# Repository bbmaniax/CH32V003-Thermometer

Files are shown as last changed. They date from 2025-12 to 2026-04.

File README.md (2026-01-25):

# Arduino: CH32V003-Thermometer

グラフ表示に対応したコンパクトな温度計です。

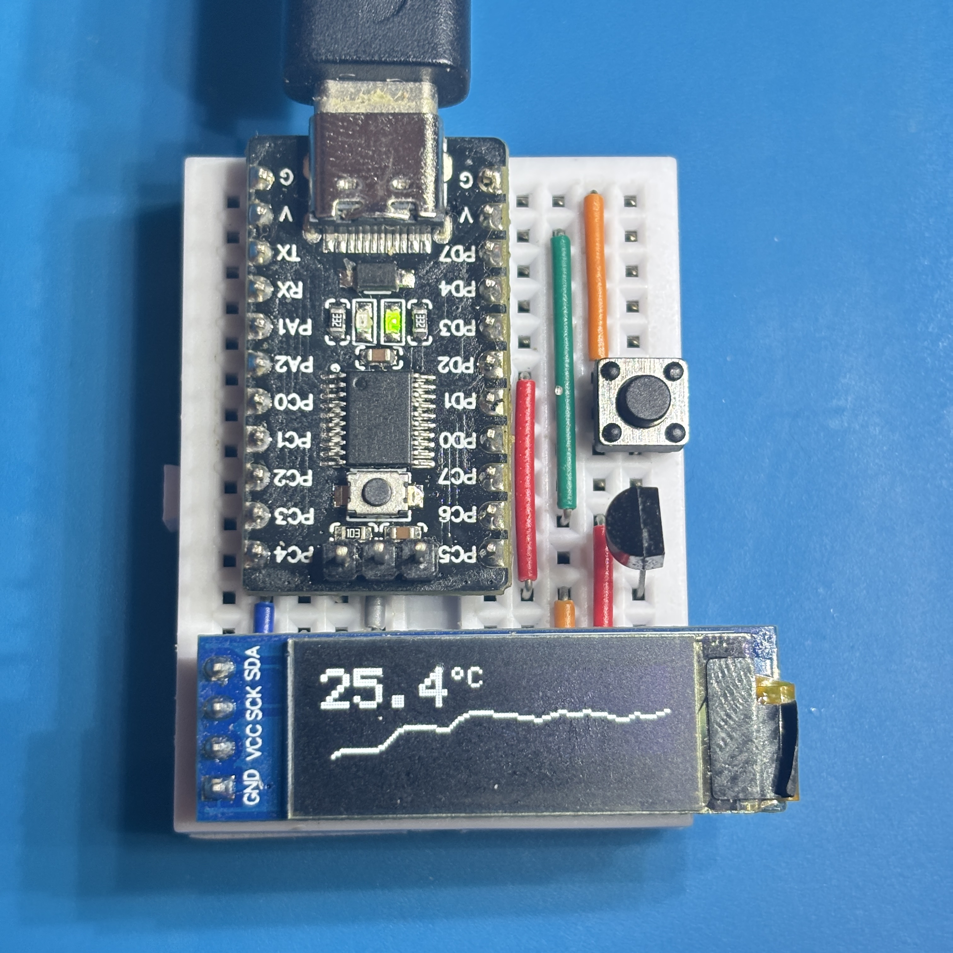
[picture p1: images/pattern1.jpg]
グラフ表示


温度のグラフ表示とテキスト表示、および上下反転表示に対応しています。

<div>
グラフ表示
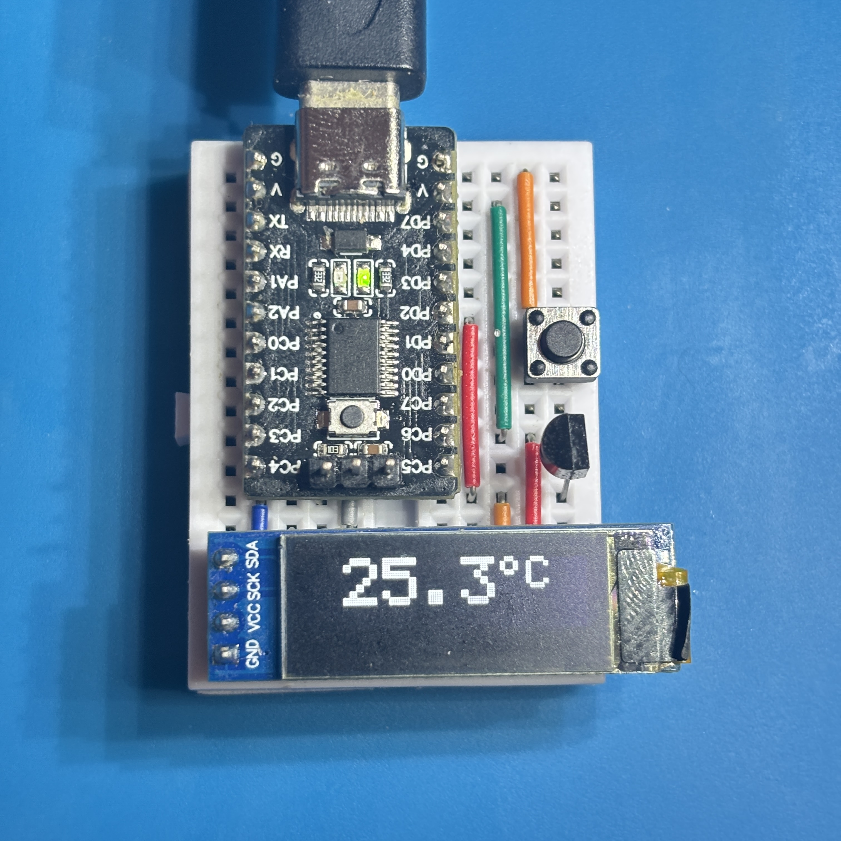
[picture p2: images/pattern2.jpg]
テキスト表示

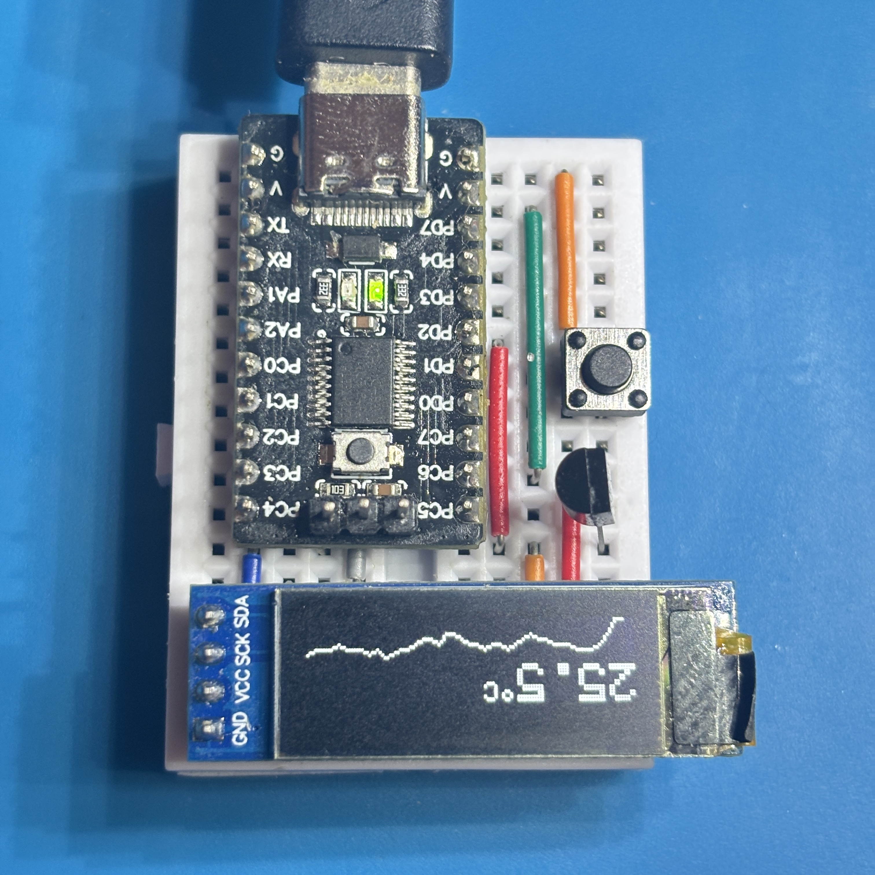
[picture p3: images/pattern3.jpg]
上下反転

</div>

## 部材

| 種別 | 型番など | 数量 |
|:-----|:---|:-----|
| ブレッドボード | 170H | 1個 |
| ジャンパーワイヤ | - | 11本 |
| タクトスイッチ | 2P 6x6mm | 1個 |
| マイコン | CH32V003 開発ボード | 1個 |
| OLED モジュール | 0.91" 128x32 | 1個 |
| 温度センサー | DS18B20 | 1個 |

## 配線図

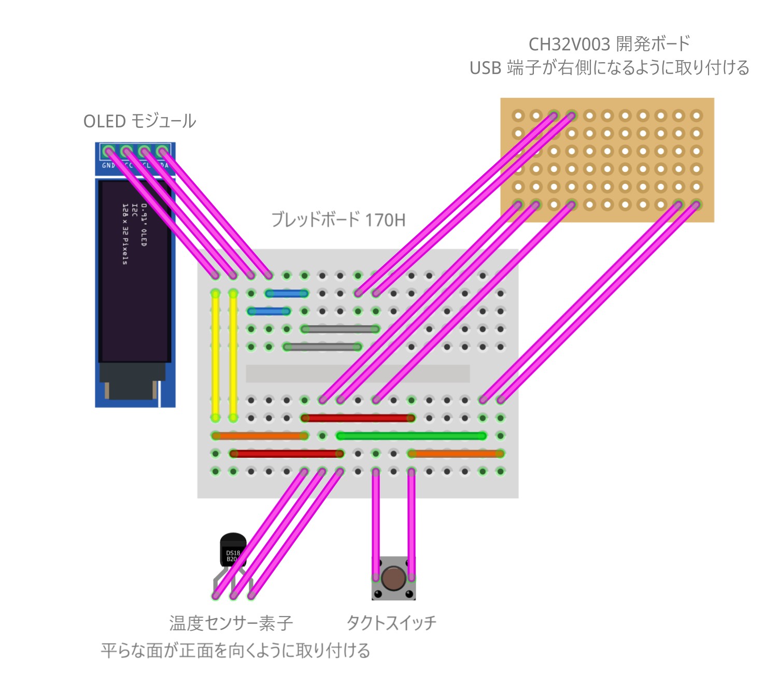
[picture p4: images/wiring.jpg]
配線図


## プログラム開発環境

### 統合開発環境

**インストール**:
1. 公式サイト [https://www.arduino.cc/en/software/#ide](https://www.arduino.cc/en/software/#ide) からダウンロード・インストール

### ボードマネージャ

**インストール**:
1. Arduino IDE の「ファイル」→「環境設定」→「追加のボードマネージャのURL」に以下を追加:
   ```
   https://raw.githubusercontent.com/ch32-riscv-ug/arduino_core_ch32_riscv_arduino/main/package_ch32-riscv-arduino.json
   ```
2. ボードマネージャーで「CH32 RISC-V Arduino」を検索し、「インストール」ボタンをクリック

### 依存ライブラリ

| ライブラリ | 説明 |
|:---|:-----|
| DigitalButton | タクトスイッチ制御 |

**インストール**: Arduino IDEのライブラリマネージャーで検索・インストール

## ビルド・書き込み手順

1. Arduino IDE で `CH32V003-Thermometer.ino` を開く
2. 「ツール」→「ボード」→「CH32 RISC-V Arduino」→「CH32V003」を選択
3. 「ツール」→「ポート」でWCH-LinkEが接続されているポートを選択
4. 画面上部の右向き矢印ボタン（アップロード）をクリック

## 操作

マイコンに電源を供給すると作動します。
定期的に温度を測定して、OLED に表示します。

ボタンを押すと、表示パターンが切り替わります。

グラフ表示
テキスト表示

ボタンを長押しすると、表示が上下反転します。

上下反転

## ライセンス

このプロジェクトは [MIT ライセンス](./LICENSE) の下で公開されています。
自由に使用、改変、再配布していただけます。

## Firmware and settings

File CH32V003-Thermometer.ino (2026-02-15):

// CH32V003-Thermometer.ino - Main sketch for CH32V003-based thermometer

#include <Arduino.h>
#include <DigitalButton.h>

#include "DS18B20.h"
#include "Model.h"
#include "OneWire.h"
#include "SSD1306.h"
#include "SensorDataHistory.h"
#include "SensorManager.h"
#include "View.h"

#define SERIAL_SPEED 115200
#define BUTTON_PIN PD0
#define DS18B20_PIN PC5
#define DS18B20_TEMPERATURE_OFFSET -9
#define DISPLAY_WIDTH 128
#define DISPLAY_HEIGHT 32
#define DISPLAY_BUFFER_SIZE (DISPLAY_WIDTH * DISPLAY_HEIGHT / 8)
#define MEASUREMENT_INTERVAL_MS 3000
#define HORIZONTAL_STEP 3
#define HISTORY_BUFFER_SIZE ((DISPLAY_WIDTH + HORIZONTAL_STEP - 1) / HORIZONTAL_STEP + 1)

uint8_t displayBuffer[DISPLAY_BUFFER_SIZE];
int16_t temperatureHistoryBuffer[HISTORY_BUFFER_SIZE];

DigitalButton button(BUTTON_PIN, true);
SSD1306 display(DISPLAY_WIDTH, DISPLAY_HEIGHT, displayBuffer);
OneWire oneWire(DS18B20_PIN, true);
DS18B20 ds18b20(oneWire, DS18B20_TEMPERATURE_OFFSET);

SensorDataHistory temperatureHistory(temperatureHistoryBuffer, HISTORY_BUFFER_SIZE);
Model model(temperatureHistory);
View view(model, display, HORIZONTAL_STEP);
SensorManager sensorManager(ds18b20, MEASUREMENT_INTERVAL_MS);

void setup() {
  // Serial.begin(SERIAL_SPEED);
  // while (!Serial && millis() < 1000);
  Serial.println();
  Serial.println("--");
  Serial.println("Thermometer (built at " __DATE__ " " __TIME__ ")");

  button.begin();
  sensorManager.begin();
  delay(100);

  model.begin();
  view.begin();
}

void loop() {
  static bool needRender = true;

  button.update();
  sensorManager.update();

  if (button.isLongPressed()) {
    view.flip();
    needRender = true;
  }

  if (button.isClicked()) {
    view.switchToNextViewMode();
    needRender = true;
  }

  if (sensorManager.consumeReady()) {
    SensorManager::SensorData data = sensorManager.getSensorData();
    printSensorData(millis(), data);
    model.update(data);
    needRender = true;
  }

  if (needRender) {
    view.render();
    needRender = false;
  }

  delay(10);
}

void printSensorData(unsigned long timestamp, const SensorManager::SensorData& data) {
  Serial.print("TS:");
  Serial.print(timestamp);
  Serial.print(" T:");
  printSensorValue(data.temperature);
  Serial.println();
}

void printSensorValue(int16_t value) {
  int16_t intPart = value / 10;
  uint8_t fracPart = abs(value % 10);

  if (value < 0 && intPart == 0) {
    Serial.print("-0.");
  } else {
    Serial.print(intPart);
    Serial.print(".");
  }

  Serial.print(fracPart);
}

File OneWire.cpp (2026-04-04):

// OneWire.cpp - Arduino library for 1-Wire communication

#include "OneWire.h"

#if defined(__AVR__)
#  define OW_DISABLE_IRQ() noInterrupts()
#  define OW_ENABLE_IRQ() interrupts()
static inline void delay_us(uint16_t us) {
  delayMicroseconds(us);
}

static inline void ow_output_low(uint8_t pin) {
  digitalWrite(pin, LOW);
  pinMode(pin, OUTPUT);
}

static inline void ow_input(uint8_t pin, bool useInputPullup) {
  if (useInputPullup) {
    digitalWrite(pin, HIGH);
    pinMode(pin, OUTPUT);
    pinMode(pin, INPUT_PULLUP);
  } else {
    pinMode(pin, INPUT);
  }
}

static inline uint8_t ow_read(uint8_t pin) {
  return digitalRead(pin) ? 1 : 0;
}
#elif defined(__riscv) && defined(CH32V003)
#  include "ch32v00x.h"
extern uint32_t SystemCoreClock;
#  define OW_DISABLE_IRQ() __disable_irq()
#  define OW_ENABLE_IRQ() __enable_irq()

static void delay_us(uint16_t us) __attribute__((noinline));

static void delay_us(uint16_t us) {
  uint32_t cycles = (uint32_t)us * (SystemCoreClock / 4000000);
  __asm__ volatile(
    "1: addi %0, %0, -1\n"
    "   bnez %0, 1b\n"
    : "+r"(cycles));
}

static inline GPIO_TypeDef* ow_get_gpio(uint8_t pin) {
  uint8_t port = (pin & CH32_GPIO_MASK) >> 5;
  switch (port) {
    case 1:
      return GPIOA;
    case 4:
      return GPIOD;
    default:
      return GPIOC;
  }
}

static inline void ow_output_low(uint8_t pin) {
  GPIO_TypeDef* gpio = ow_get_gpio(pin);
  uint8_t pinNum = pin & CH32_PIN_MASK;
  uint8_t shift = pinNum * 4;
  gpio->BSHR = (1 << (pinNum + 16));
  gpio->CFGLR = (gpio->CFGLR & ~(0xFUL << shift)) | (0x3UL << shift);
}

static inline void ow_input(uint8_t pin, bool useInputPullup) {
  GPIO_TypeDef* gpio = ow_get_gpio(pin);
  uint8_t pinNum = pin & CH32_PIN_MASK;
  uint8_t shift = pinNum * 4;
  if (useInputPullup) {
    gpio->BSHR = (1 << pinNum);
    gpio->CFGLR = (gpio->CFGLR & ~(0xFUL << shift)) | (0x3UL << shift);
    gpio->CFGLR = (gpio->CFGLR & ~(0xFUL << shift)) | (0x8UL << shift);
  } else {
    gpio->CFGLR = (gpio->CFGLR & ~(0xFUL << shift)) | (0x4UL << shift);
  }
}

static inline uint8_t ow_read(uint8_t pin) {
  GPIO_TypeDef* gpio = ow_get_gpio(pin);
  uint8_t pinNum = pin & CH32_PIN_MASK;
  return (gpio->INDR & (1 << pinNum)) ? 1 : 0;
}
#else
#  error "Not supported"
#endif

OneWire::OneWire(uint8_t pin, bool useInputPullup) : pin(pin), useInputPullup(useInputPullup) {
}

void OneWire::begin(void) {
  ow_input(pin, useInputPullup);
}

uint8_t OneWire::reset(void) {
  uint8_t r;
  uint8_t retries = 125;

  OW_DISABLE_IRQ();

  ow_input(pin, useInputPullup);
  while (ow_read(pin) == 0) {
    if (--retries == 0) {
      OW_ENABLE_IRQ();
      return 0;
    }
    delay_us(2);
  }

  ow_output_low(pin);
  delay_us(480);

  ow_input(pin, useInputPullup);
  delay_us(70);
  r = (ow_read(pin) == 0) ? 1 : 0;
  delay_us(410);

  OW_ENABLE_IRQ();
  return r;
}

void OneWire::skip(void) {
  write(0xCC);
}

void OneWire::write_bit(uint8_t v) {
  OW_DISABLE_IRQ();
  if (v & 1) {
    ow_output_low(pin);
    delay_us(10);
    ow_input(pin, useInputPullup);
    delay_us(55);
  } else {
    ow_output_low(pin);
    delay_us(65);
    ow_input(pin, useInputPullup);
    delay_us(5);
  }
  OW_ENABLE_IRQ();
}

uint8_t OneWire::read_bit(void) {
  uint8_t r;

  OW_DISABLE_IRQ();
  ow_output_low(pin);
  delay_us(1);
  ow_input(pin, useInputPullup);
  r = ow_read(pin);
  delay_us(60);
  OW_ENABLE_IRQ();

  return r;
}

void OneWire::write(uint8_t v, uint8_t power) {
  for (uint8_t bitMask = 0x01; bitMask; bitMask <<= 1) {
    write_bit((bitMask & v) ? 1 : 0);
  }
  if (!power) {
    ow_input(pin, useInputPullup);
  }
}

uint8_t OneWire::read(void) {
  uint8_t r = 0;
  for (uint8_t bitMask = 0x01; bitMask; bitMask <<= 1) {
    if (read_bit()) {
      r |= bitMask;
    }
  }
  return r;
}

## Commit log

2026-01-18 change: sensor value scaling
2026-02-15 Refactor/20260214 (#4)
    * add: AGENTS,md
    * fix: spell(s)
    * fix: SendorManager.isReady()
    * fix: OneWire.begin()
    * fix: delete unnecessary include(s)
    * fix: use CHAR_DEGREE
    * update: AGENTS.md
    ---------
    [CH32V003-Thermometer.ino, DS18B20.cpp]
2026-04-04 update/2026-03-29 (#6)
    * update: Makefile and arduino-ci.yaml
    * update: use IRQ enable/disable in OneWire
    * fix: Makefile
    * fix: arduino-ci.yaml
    * fix: Makefile
    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
    [OneWire.cpp]
